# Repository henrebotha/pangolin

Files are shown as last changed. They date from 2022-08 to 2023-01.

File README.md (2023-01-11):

# Pangolin

Pangolin is an open system for designing & building custom game controllers, initially aimed at (but not limited to) controllers for competitive fighting games.

For now, this contains the files needed to produce the "default configuration", an all-button controller in the style of a Hit Box, measuring 270×165×26 mm. More to come.

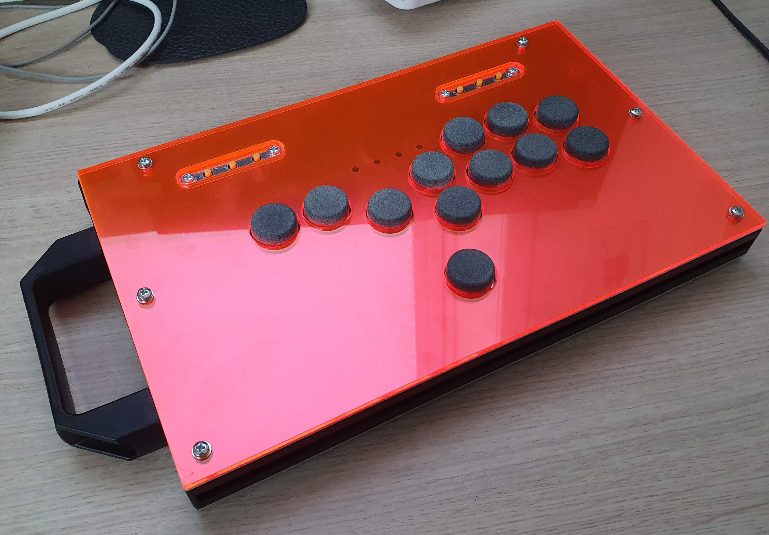
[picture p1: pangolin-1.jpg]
An example Pangolin build


## Files

The `cad` directory contains CAD project files used to generate the designs for printing, cutting, etc.

The `parts` directory contains the files for manufacturing the parts for the default build.

## Shopping list

### Enclosure

The DXF and STL files in this repo need to be manufactured.

The STL should be 3D printed in any material of your choice; I used PA12 SLS. It's a load-bearing part, so you want it to be reasonably strong. You just need to print 1× copy of this file; the file contains three brackets that you will cut apart.

The DXF files need to be either laser cut or manufactured by hand. You need 1× of each. All of the files except the acrylic top panel must be 1.5–1.6 mm thick. Metal (aluminium, brass, steel…) or FR4 (the stuff PCBs are made of) are good options for the switch plate. I recommend aluminium for the other panels. The top panel "acrylic" file can be any material you want, but people usually go with transparent acrylic; this allows you to install art of your choosing. It should be 3 mm thick.

Then you need to get 20×20 mm aluminium extrusions (aka 8020 profiles, T-slot structural framing…) cut to the following lengths (most places that sell these will cut them for you):

| Length | Quantity|
| --- | --- |
| 265 mm | 1× |
| 125 mm | 2× |
| 89 mm | 2× |

You also need 4× little gusseted brackets (see [this image](./bracket.png)) measuring about 20×20×20 mm, appropriate hardware for fixing them to the extrusions, and some end caps for the extrusions. All of these things can be bought from places that sell aluminium extrusions, including but not limited to: Motedis, 8020, Aluxprofiel…

You will need M3 bolts to assemble this build. A length of about 8 mm is appropriate for the top panels, and about 6 mm for the bottom and the connector panel. You will need M3 nuts for connecting the switch plate to the brackets. You will also need twist-in M3 T-nuts to hold the various bolts in the frame.

You will need 6 mm M3 spacer bolts for attaching the auxiliary buttons PCBs to the control panel at the correct height, along with some M3 nuts and 4 mm M3 bolts.

### Electronics

You will need 12× keyboard switches in the MX form factor. [There are many out there](https://switches.mx/switches); what you choose will be a matter of personal preference. If you're not sure what to pick, a linear switch (often identified as Black, Red, or Silver) is a great starting point.

You will need 12× round keycaps to fit these switches. The control panel has 22 mm cutouts, which means you should use keycaps less than 21 mm in diameter. I recommend [these](https://github.com/rana-sylvatica/circle-keycaps), which you can have printed cheaply in MJF PA12 nylon at JLCPCB & which feel fantastic to use. (Note that other keycaps might not be the same height; this can be a problem if you use shallower caps, as they will not protrude an appropriate distance from the control panel, and therefore be annoying to press.)

You will need some wire to connect the keyboard switches to your encoder of choice. Optionally, you may also want to obtain 12× single-switch PCBs (such as Amoebas, [Model-MX1S](https://github.com/HTangl/MX1S), etc), as these will allow you to make the switches hot swappable (and soldering these PCBs, if you need to do it yourself, is easier than soldering directly to switches).

You will need 2× auxiliary button PCBs. The files for them can be found [here](https://github.com/henrebotha/aux-buttons-pcb/). They can be manufactured and assembled completely by JLCPCB; you don't need to do any soldering yourself.

You will need 2× 4-wire JST-PH cables to connect the auxiliary button PCBs to your encoder of choice. You can find these on Amazon and elsewhere.

You will need an encoder PCB. The enclosure is nominally designed to accept a Brook Fighting Board, but in its present form, this is an incredibly tight fit. You will need to use the absolute lowest-profile mounting for this that you can manage; perhaps nano tape? Even very low-profile adhesive PCB feet are too tall and will cause the USB port to be stressed as it presses into the switch plate. Should you opt for a Brook with a headphone jack, there is a hole on the control panel sized to accept a 3.5 mm panel-mount jack (which you will have to solder yourself — the jack that comes with these Brook boards is not accommodated). Similarly, if you opt for a Brook Wireless, there is a hole sized to fit the antenna. A Raspberry Pi Pico running the best-in-class open source [GP2040 firmware](https://github.com/OpenStickFoundation/GP2040-CE) is an excellent alternative to a Brook, and is much, much more compact, but requires soldering (though perhaps you can find one with convenient headers, screw terminals, etc). (If you want to use "DuPont" wires on a Pico with headers, note that the connectors will end up making the Pico more than 20 mm tall, exceeding the available internal space; you will have to bend the header pins in order to fit the Pico in the enclosure.)

You will need a panel-mount USB passthrough similar to the [Adafruit 907](https://www.adafruit.com/product/907) (Brook) or [Adafruit 937](https://www.adafruit.com/product/937) (Pico). Variations on this can be found on Amazon, Aliexpress, etc, with slightly varying dimensions (particularly mounting hole distance). The connector panel _should_ accommodate most of these, but only the Adafruit ones have been explicitly tested for fit.

You can optionally get a [Player LEDs PCB](https://bitbanggaming.com/products/player-leds-pcb) from Bit Bang Gaming; the control panel has mounting holes for the screws & holes for the light pipes.

# Community

This project has a dedicated [Discord server](https://discord.gg/UYDxp4wrGX), which is the best place to ask for help, give feedback, or just show off what you've built.

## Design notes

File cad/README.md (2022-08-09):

# CAD files

In this document, the term "2D parts" refers to parts that would typically manufactured from sheets or panels, e.g. laser cutting acrylic. "3D parts" refers to parts that would typically be manufactured in three dimensions, e.g. 3D printed, CNC milled, carved by hand from wood, etc.

The `cad` directory contains the FreeCAD project used to design the 2D parts. It was produced using [realthunder's branch of FreeCAD](https://github.com/realthunder/FreeCAD/tree/LinkStage3), which is a version that has many usability improvements over the mainline version. However, it may be deprecated soon. It is unclear at this moment whether mainline FreeCAD will be able to open the project files; if you try to do so and are unable, please create an issue on GitHub.

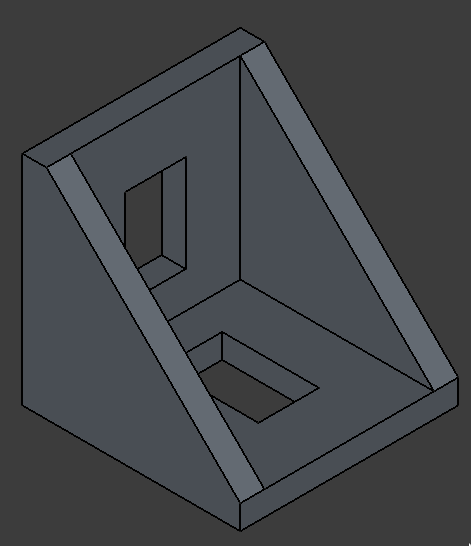
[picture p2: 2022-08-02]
bracket.png

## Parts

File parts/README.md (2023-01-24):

# Parts

In this document, the term "2D parts" refers to parts that would typically manufactured from sheets or panels, e.g. laser cutting acrylic. "3D parts" refers to parts that would typically be manufactured in three dimensions, e.g. 3D printed, CNC milled, carved by hand from wood, etc.

In 2D, you will find DXF files that are compatible with most laser cutting services. The files there are all to be cut from 1–2 mm aluminium (or a similarly strong material), except for the one with `Acrylic` in the name, which is to be cut from 1–4 mm acrylic (or any other aesthetically-pleasing material that feels good to the touch).

In 3D, you will find an STL file that can be used to 3D print the part. It may also be possible to produce it through CNC machining or other techniques. If you choose to 3D print it, favour structural soundness over aesthetics; it's an internal part, so you won't see it, and it has to hold the switch plate up against your playing, so it needs to be strong. SLS PA12 is a good option.

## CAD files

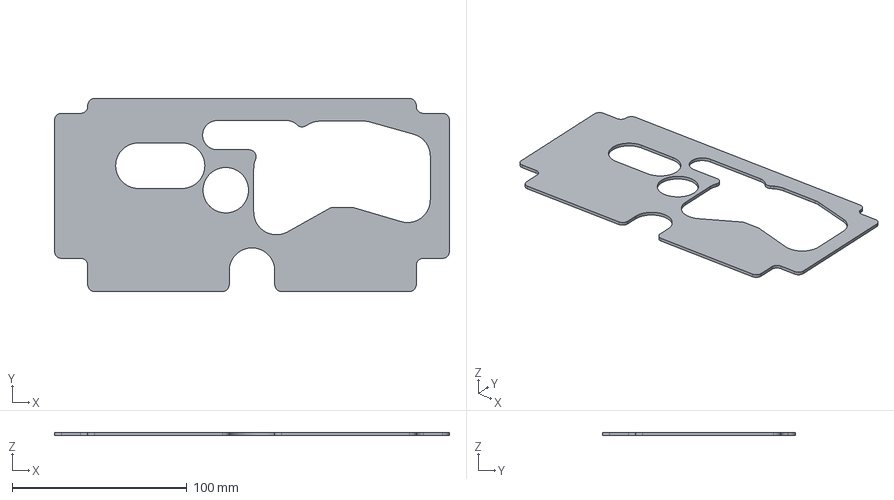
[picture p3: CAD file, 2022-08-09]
cad/panels.FCStd
226.0 x 110.5 x 2.00 mm

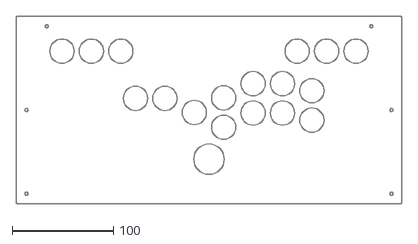
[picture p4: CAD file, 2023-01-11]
parts/2d/24-30/24-30-TopPanel.dxf
380.0 x 185.0

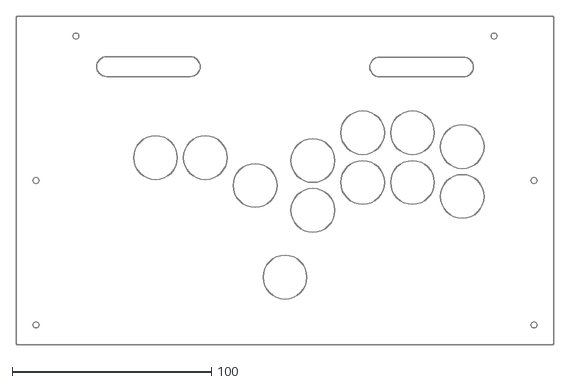
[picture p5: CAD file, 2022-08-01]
parts/2d/TopPanel_Acrylic.dxf
270.0 x 165.0

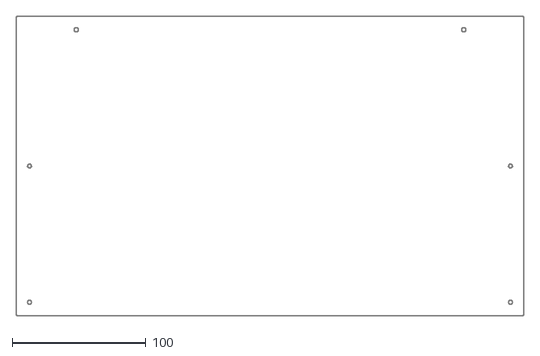
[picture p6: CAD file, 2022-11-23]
parts/2d/vewlix/vewlix-BottomPanel.dxf
380.0 x 224.0

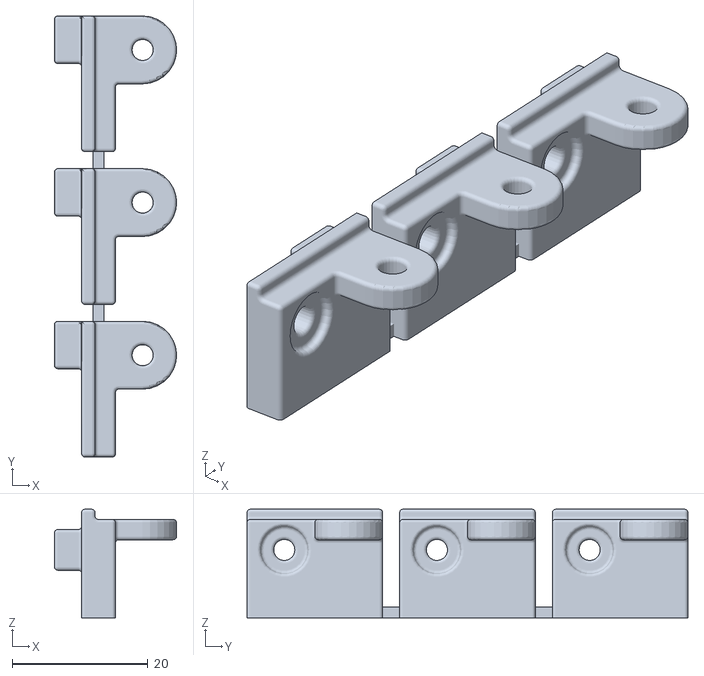
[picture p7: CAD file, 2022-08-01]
parts/3d/Standoff_Sprued.stl
18.0 x 65.0 x 16.0

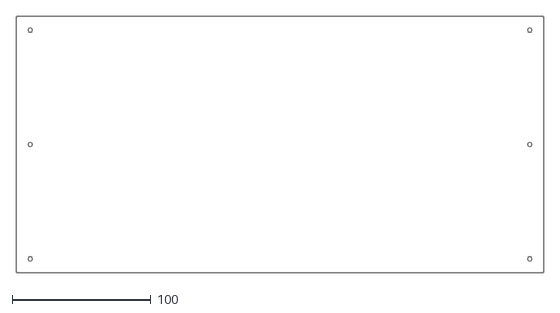
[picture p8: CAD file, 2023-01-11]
parts/2d/24-30/24-30-BottomPanel.dxf
380.0 x 185.0

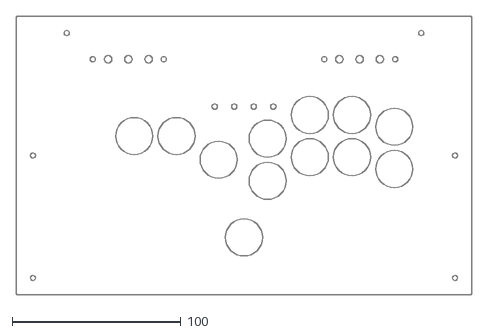
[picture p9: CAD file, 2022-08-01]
parts/2d/TopPanel.dxf
270.0 x 165.0

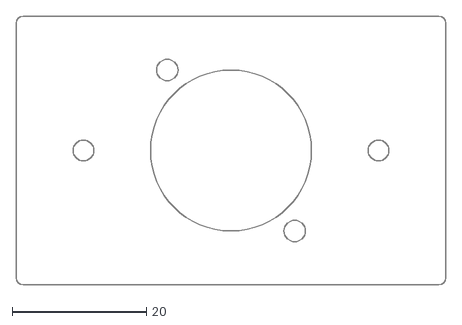
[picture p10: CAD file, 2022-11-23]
parts/2d/vewlix/vewlix-ConnectorPanel.dxf
64.0 x 40.0

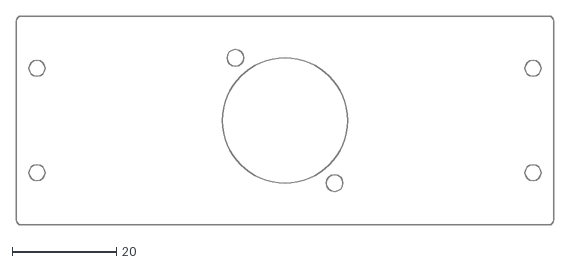
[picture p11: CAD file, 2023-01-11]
parts/2d/24-30/24-30-JackPanel_Neutrik.dxf
103.0 x 40.0

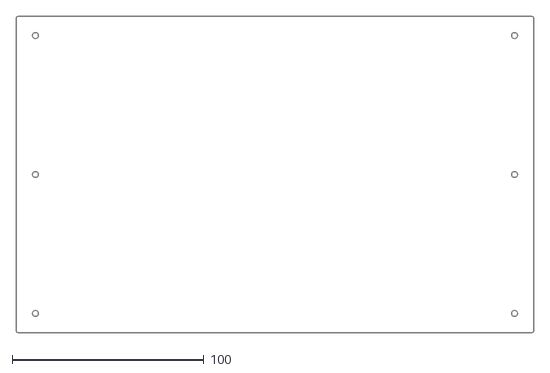
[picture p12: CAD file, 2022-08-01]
parts/2d/BottomPanel.dxf
270.0 x 165.0

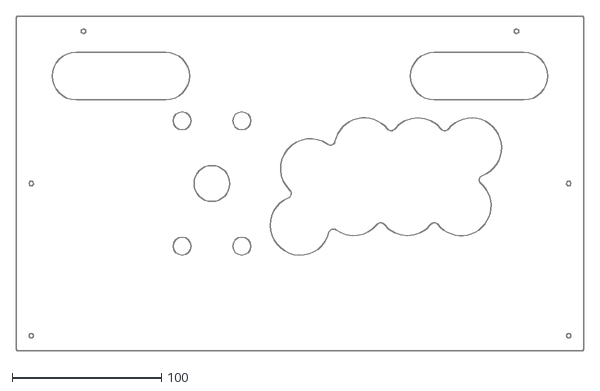
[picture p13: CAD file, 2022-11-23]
parts/2d/vewlix/vewlix-TopPanel_Acrylic.dxf
380.0 x 224.0

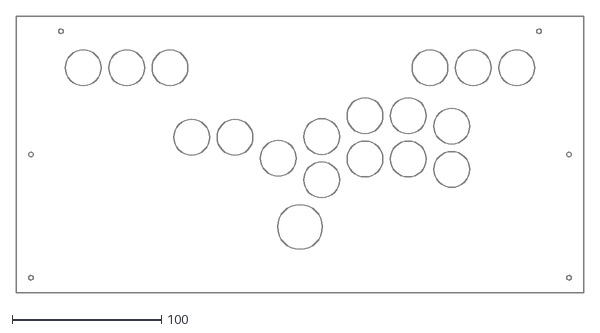
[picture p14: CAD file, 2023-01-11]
parts/2d/24-30/24-30-TopPanel_Acrylic.dxf
380.0 x 185.0

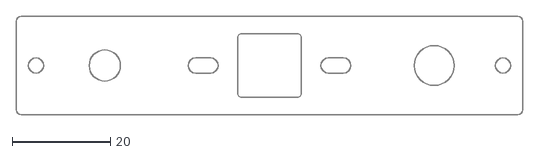
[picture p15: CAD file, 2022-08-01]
parts/2d/JackPanel.dxf
103.0 x 20.0

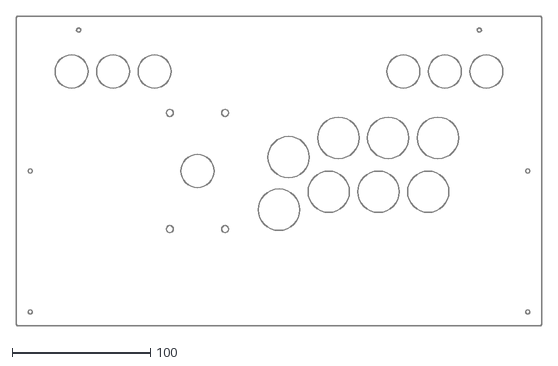
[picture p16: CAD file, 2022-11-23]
parts/2d/vewlix/vewlix-TopPanel.dxf
380.0 x 224.0

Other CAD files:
parts/2d/24-30/24-30-TopPanel_Snap-in.dxf
parts/2d/SwitchPlate.dxf
parts/2d/24-30/24-30-JackPanel.dxf

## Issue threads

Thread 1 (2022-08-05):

Brook Fighting Board is difficult to fit

henrebotha, 2022-08-05:
In the current version of the design, there's a cutout in the switch plate to leave space for a Brook Fighting Board. However, it's a very tight fit. There's _just_ enough room for the USB cable to pass between the U and R buttons. And the board must be mounted using something extremely low profile; even the shortest PCB feet I was able to find are too thick, causing stress on the USB port.

One potential improvement is to change the switch plate from its current "T" shape to something like a sideways "J". In other words, connect the U button to the other buttons from the far right, not in the middle. This should open up a tiny bit more space.

One could also mount the U button on an entirely separate tiny switch plate to achieve something similar. This would require more hardware though. One would also need to consider how then to fix the north-south positioning of the main switch plate.

henrebotha, 2022-10-03:
To clarify what I meant, I am suggesting changing the switch plate shape from roughly this…

```
┌──────────────┐
│              │
└─────┐  ┌─────┘
      │  │
      └──┘
```

…to roughly this.

```
┌──────────────┐
│              │
└───────────┐  │
      ┌─────┘  │
      └────────┘
```

Doing so might create a gap between the main section and the thumb button, allowing the Brook board to be mounted such that its tallest parts can poke through that gap. This needs to be verified in CAD though.

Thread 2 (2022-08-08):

Accessory: adapter dongle holder

henrebotha, 2022-08-08:
A nice 3D printed holder for a USB adapter dongle would be pretty neat. It could be bolted to the extrusions on the outside.

Some adapters to explicitly support:

- Brook range (Wingman and Super Converter)
- Mayflash Magic range

I'll hopefully be getting a Wingman XE soon, so I might be able to take some measurements.

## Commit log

2022-08-02 Add image of bracket
2022-08-09 Add FreeCAD project
    Also add & improve documentation around the files.
    [BottomPanel.dxf, JackPanel.dxf, Standoff_Sprued.stl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]
2022-10-03 Expand on Pico encoder
2022-11-20 Fix switches.mx hyperlink
2022-11-23 Add drawings for Vewlix build
    [vewlix-BottomPanel.dxf, vewlix-ConnectorPanel.dxf, vewlix-TopPanel.dxf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]
2023-01-11 Add drawings for classic build
    [24-30-BottomPanel.dxf, 24-30-JackPanel.dxf, 24-30-JackPanel_Neutrik.dxf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]
